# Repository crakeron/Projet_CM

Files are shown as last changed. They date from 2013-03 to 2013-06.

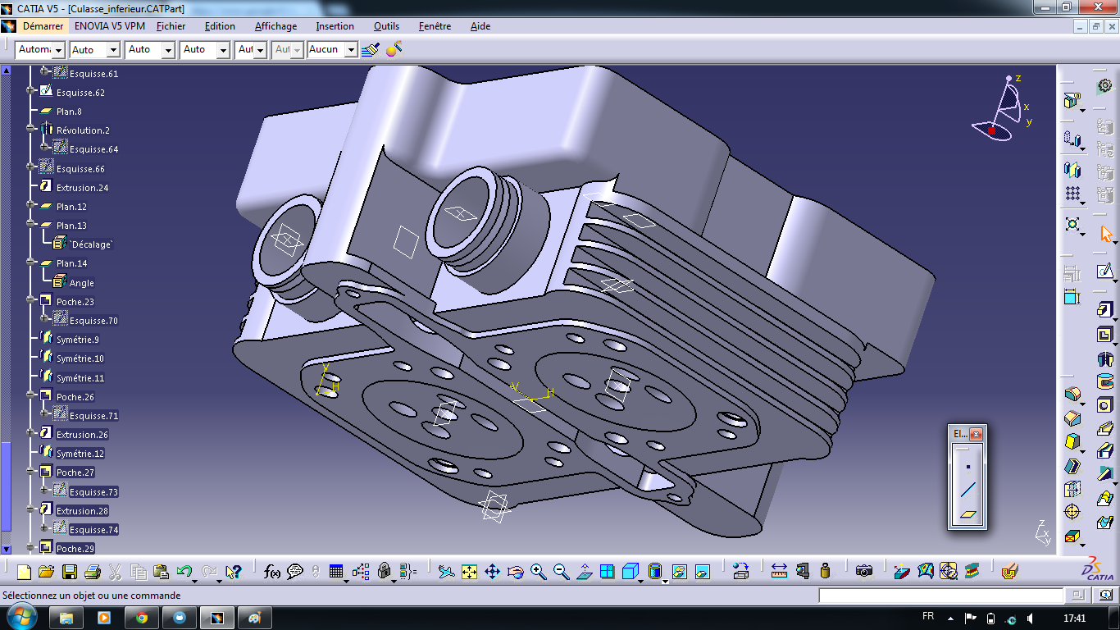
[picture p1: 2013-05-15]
Catia_GPZ500/Photos/7mai_3.png

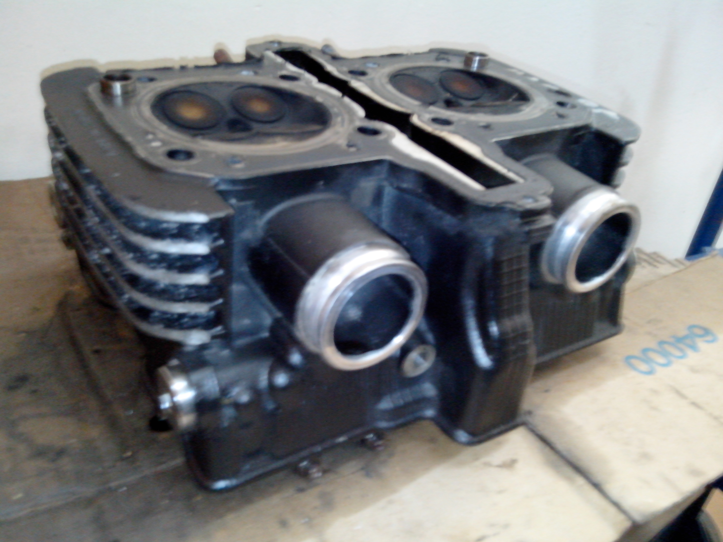
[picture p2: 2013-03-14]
Catia_GPZ500/Photos/Culasse/Culasse.jpg

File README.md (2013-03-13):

Projet_CM
=========

Projet de moteur à soupapes rotatives

Il s'agit ici de fichiers pour le logiciel DS CATIA (V6R20)
Il faut modifier UN SEUL fichier à la fois puis le synchroniser, sinon en cas de retour en arriere, tout un ensemble de 
fichiers differents seront effacés lors du retour en arriere.
.

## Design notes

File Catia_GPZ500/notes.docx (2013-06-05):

Chanfrein pour limiter pertes régulieres en admission/echappement

Pression à l’explosion : contrainte fléchissante. (Effort 10 000N à la détonation)

Rapport de compression : 9.5 -> Pression max ~9.5MPa.

## Section d’admission

Section d’amission à respecter (d’origine) : 2x π.(0.006)²= 2.26.10⁻⁴ m².

AOA à respecter : 22° avant ouverture complète , RFA à respecter : 22° après ouverture complète

Soit en surface latérale, pour un tube de 15mm de rayon :

B=15mm*sin(22°)=5.6mm.

A à calculer pour respecter la section d’admission.

S=π*A*B=2.26.10⁻⁴ m² -→ A=2.26.10⁻⁴ m²/(0.0056*π)=1,3.10⁻² m=13mm

# Dilatation thermique

Pour 100°C<T<390°C : acier a=1,7.10-5 K⁻¹ aluminium : a=2,3.10⁻⁵

dilatation du tube : e=2.5mm. ΔL=1,7.10-5 K⁻¹*(300+273)*2.5=0.02mm

dilatation du chapeau aluminium : ΔL=2,3.10⁻⁵*(300+273)*7=0.9mm

## Joint tresse 3x3 http://www.carrara.it/products.php?main=001&category=030&product=26

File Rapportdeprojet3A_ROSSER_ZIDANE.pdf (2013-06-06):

# Rapport de projet Distribution rotative d’un moteur 4 temps

### Réalisé par :

### - ROSSER Marc - ZIDANE Salim

### Responsable du projet :

### - M.DARCISSAC Sylvain

2012/2013

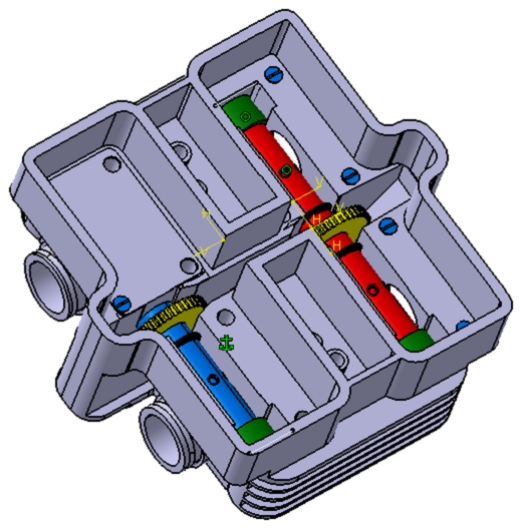
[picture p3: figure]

## 1 ZIDANE Salim – ROSSER Marc

## Sommaire :

I- Introduction : | Erreur ! Signet non défini.
II- Le moteur étudié : | 3
1) Presentation du moteur GPZ500 | 3
2) Données antérieures | 3-4
3) Modélisation du bloc cylindre | 4
III- Système et Assemblage : | 5
IV- Conception : | 7
1) Conception de la culasse | 7
2) Conception du circuit de refroidissement | 9
3) Conception du tube | 10

## 4) Conception des chapeaux d’admission et d’echappement | 11

5) Choix des engrenages | 12
6) Choix des roulements | 14
7) Choix des joints d’etanchéité | 15
V- Conclusion : | 16
ANNEXES | 17-23

## VI- Impression 3D

…24

## 2 ZIDANE Salim – ROSSER Marc

# I Introduction

Dans le cadre de notre préparation au diplôme d'ingénieur en mécanique et conception des systèmes, nous avons été amenés à effectuer notre projet de troisième année sous l’encadrement de M. Sylvain Darcissac.

Ceci est notre premier gros projet, et s’inscrit dans la continuité d’un projet antérieur effectué par un binôme de 5

ème année. Leur projet consistait à supprimer d’un moteur ses soupapes et de les remplacer par un système rotatif. Le moteur en question était un petit moteur de débroussailleuse Honda GX25, monocylindre et à refroidissement à air.

Cette année, nous avions la tache d’imaginer un système rotatif pour l’admission et l’échappement pour un moteur différent. Dans notre cas c’est un vrai moteur de moto, celle du Kawasaki GPZ500.

Plusieurs facteurs sont venus compliquer notre tâche. Premièrement, le moteur n’est plus mono mais bicylindre. Deuxièmement, la taille du moteur (498cm³

), loin des 25cm³
du GX25,
en fait une machine dont la puissance, la chaleur et les forces de détonation sont impérativement à prendre en compte. Enfin, le moteur que nous avons étudié comporte un circuit de refroidissement liquide interne, dont il a fallu reproduire l’effet au mieux.

Conséquence de toutes les différences avec le projet précédent, il était impossible de s’inspirer directement de nos anciens. Nous avons alors imaginé et conçu notre propre système rotatif, présenté dans ce compte rendu.

## Remerciements :

Nous remercions tout d’abord les enseignants qui nous ont encadrés, Sylvain Darcissac et Damien Joli.

Nous tenons également à exprimer notre profonde gratitude à Bernard Brisson, Alain Viale et Michel Roche pour leur attention particulière ainsi que les conseils qu’ils nous ont accordés lors de la réalisation de ce projet. Leur expérience dans la mécanique nous a été d’une grande aide.

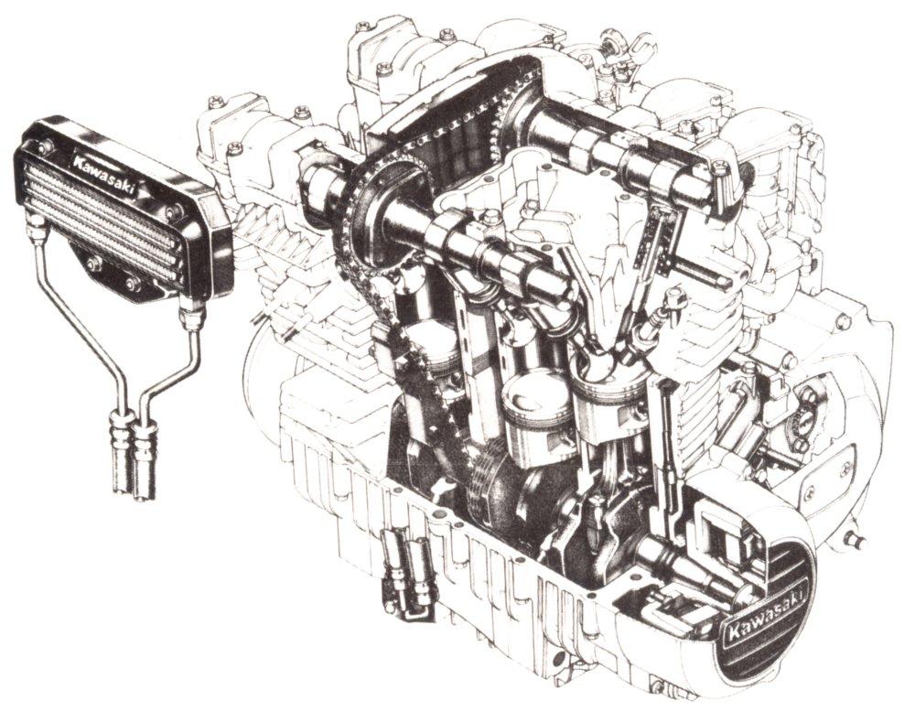
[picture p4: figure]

## 3 ZIDANE Salim – ROSSER Marc

# II. Le moteur étudié

## 1. Présentation

Pour réaliser notre étude et pour servir de base pour notre projet, nous nous sommes servis d’un moteur de Kawasaki GPZ500 (Figure 1)

Il s’agit d’un moteur bicylindre à essence, à refroidissement liquide.

Figure 1 : Le moteur GPZ 500

Figure 2 : Double arbre à came en tête (DOHC)

Les deux arbres à cames sont entraînés en rotation via une chaine de distribution entrainée à partir de l’arbre moteur.

## 2. Données antérieures

D’après les calculs faits par nos camarades plus âgés en 5

ème année, le système actuel de distribution à soupapes engendrerait une perte proche des 7% de la puissance totale d’un moteur (7,7% pour leur moteur de débroussailleuse Honda GX25).
En revanche, les pertes par frottements dues à la rotation de pièces dans leur système était de l’ordre de 0,2% de la puissance totale de leur moteur.
C’est pour cette raison que l’on nous a demandé d’adapter ce système sur un moteur plus gros et à plusieurs cylindres : la GPZ500.

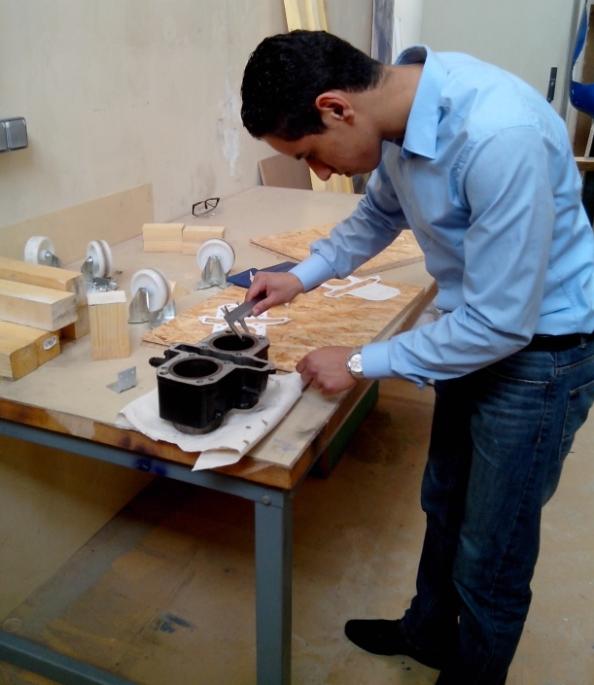
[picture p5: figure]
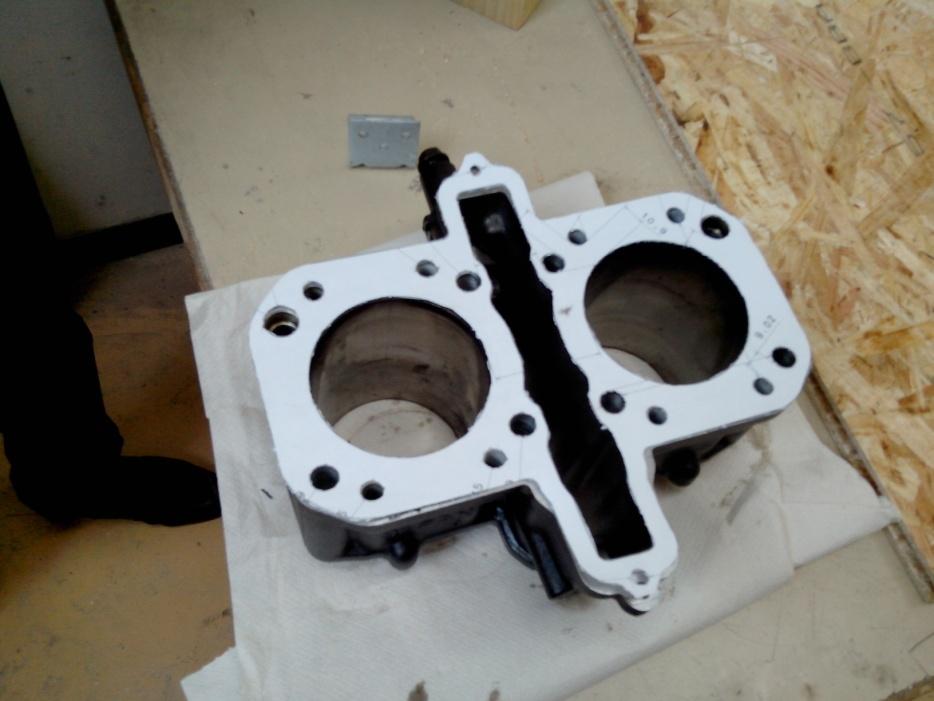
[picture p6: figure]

## 4 ZIDANE Salim – ROSSER Marc

## 3 Modélisation du bloc cylindre

Au cours du projet nous avions eu à concevoir une culasse qui viendrait remplacer celle existante. Il nous fallait être surs de pouvoir fixer celle-ci au moteur. Dans un premier temps, à l’aide d’outils de mesure, nous avions modélisé le bloc moteur en nous concentrant sur sa partie supérieure. Il était impératif que tout soit aligné entre partie supérieure du bloc et partie inférieure de la culasse.

De nombreuses mesures au pied à coulisse ont été nécessaires à la modélisation du bloc moteur, faute de plan disponible

Après impression à l’échelle 1 :1 du plan supérieur de notre modélisation et comparaison avec l’existant, nous sommes satisfaits de la correspondance parfaite

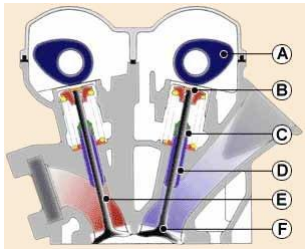
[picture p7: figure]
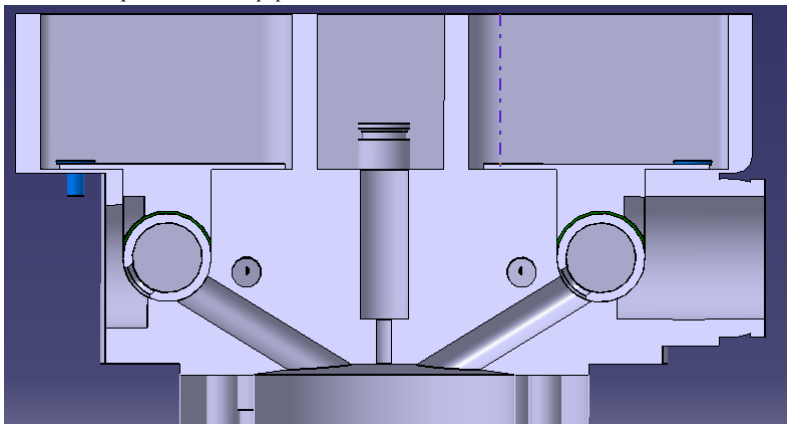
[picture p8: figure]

## 5 ZIDANE Salim – ROSSER Marc

# III Système et Assemblage

## 1) Principe de fonctionnement

Dans un moteur à distribution classique, l’admission et l’échappement sont assurées par des soupapes. Leur ouverture et leur fermeture permettent aux carburant et gaz d’échappement d’entrer ou sortir de la chambre de combustion.

Leur ouverture est assurée par la rotation de l’arbre à cames et ses palets (A). Les soupapes sont mises en translation de quelques millimètres et laissent passer les gaz qu’ils bloquaient.

Dans notre système, des tubes creux ayant une ouverture elliptique sont mis en rotation. Lorsque cette ouverture donne sur la chambre, les fluides contenus dans le tube sont libres de circuler vers celle-ci.

Lorsque le tube est tourné autrement, il bloque l’embouchure et par conséquent remplit le rôle de
« fermeture » qu’aurait une soupape.

Plan de coup de l’accès à la chambre : Le tube de droite correspond à une soupape « ouverte », tandis que le tube de gauche correspond à une soupape fermée. La descente au centre correspond à l’emplacement de la bougie.

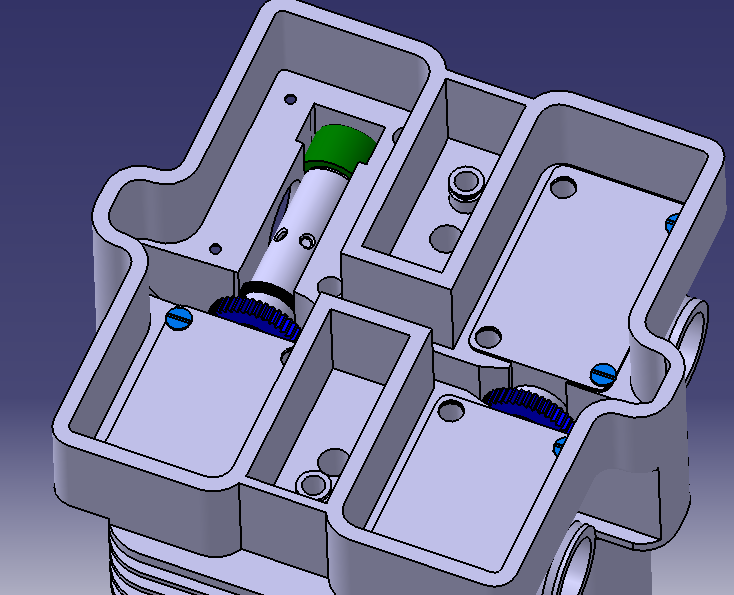
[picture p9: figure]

## 6 ZIDANE Salim – ROSSER Marc

Notre système est constitué de 2 tubes vus ci-dessus, de deux pignons transmettant à ces derniers la rotation de l’arbre moteur, de quatre roulements à aiguilles ainsi que de plusieurs pièces assurant une étanchéité (Joints en carbone, chapeaux de fermeture) et d’une culasse pour loger le tout.

Le cylindre de gauche est en phase d’admission. On y observe l’ouverture elliptique du tube orientée face à l’embouchure de la culasse, permettant ainsi la circulation du gaz depuis l’intérieur du tube vers la chambre en bas. Le cylindre de droite, lui, est fermé : le tube bloque l’embouchure.

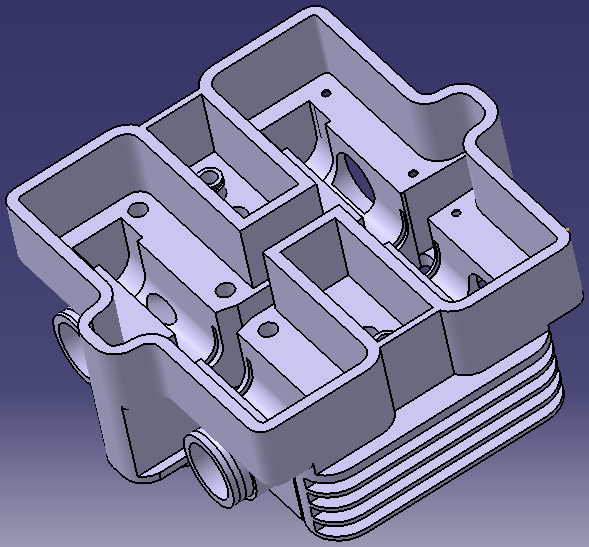
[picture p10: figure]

## 7 ZIDANE Salim – ROSSER Marc

# IV CONCEPTION

## 1) Culasse

La culasse est la pièce principale de notre assemblage. Elle est en aluminium, comme la culasse d’origine et abrite tout le système d’admission.

La taille et la forme des canaux d’admission/échappement ont été calculées afin de respecter celle de la culasse d’origine, afin de laisser suffisamment de carburant entrer dans la chambre par exemple, tout en étant limités par l’encombrement et les avances/retards à la distribution imposées par le constructeur.

L’entrée et l’admission d’origine était assurée par 4 sections circulaires par chambre de combustion (2 chacune. 8 au total pour les deux cylindres) de diamètre 12mm. Nous devions donc choisir une section limitée à 2. π. (6mm)

2 = 226mm² pour chaque fonction.

De plus Kawasaki indique une avance avant ouverture complète et un retard avant fermeture de ± 22°. Sur la section latérale de notre tube de distribution cela ne représente qu’une différence de hauteur de 5,6mm :

Le seul moyen de respecter l’aire avec une hauteur diminuée fut de prendre une forme elliptique dont les dimensions sont les suivantes :

Après conversion en mètres, le calcul de la demi-longueur A de l’ellipse donne A=13mm.

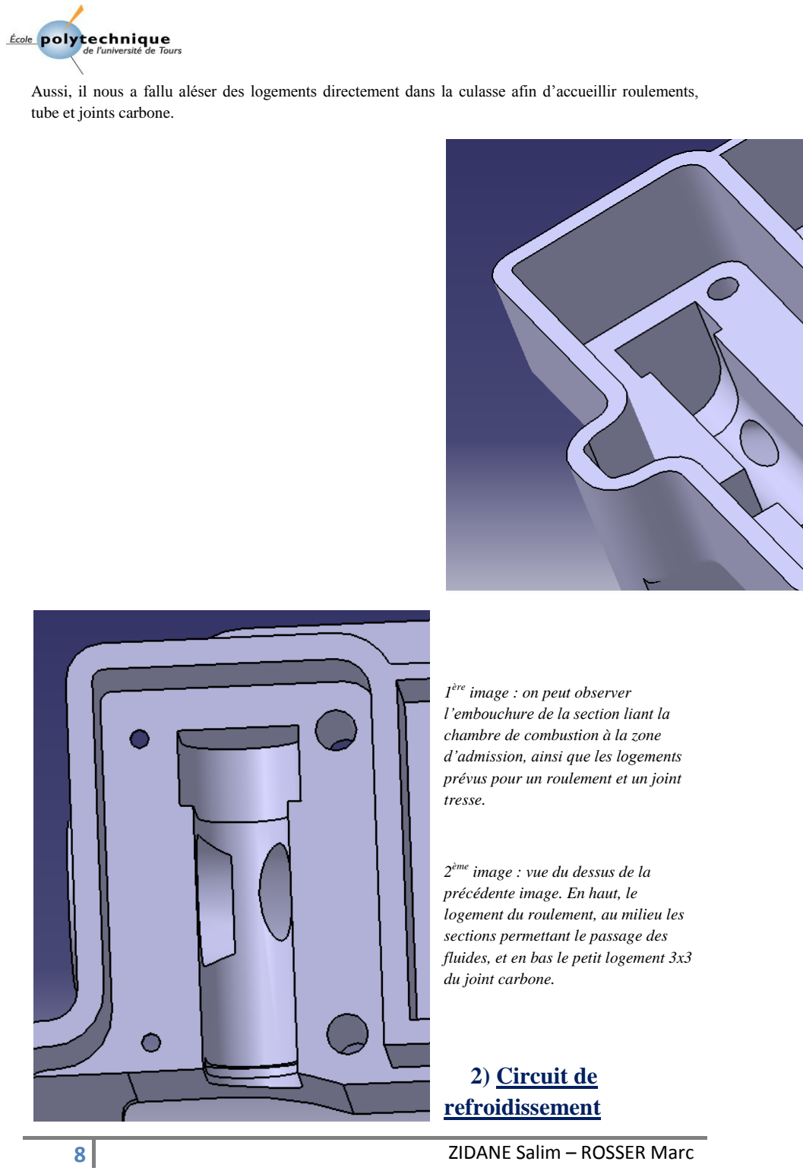
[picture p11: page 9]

## 8 ZIDANE Salim – ROSSER Marc

Aussi, il nous a fallu aléser des logements directement dans la culasse afin d’accueillir roulements, tube et joints carbone.

1

ère image : on peut observer l’embouchure de la section liant la chambre de combustion à la zone d’admission, ainsi que les logements prévus pour un roulement et un joint tresse.

2

ème image : vue du dessus de la précédente image. En haut, le logement du roulement, au milieu les sections permettant le passage des fluides, et en bas le petit logement 3x3 du joint carbone.

## 2) Circuit de refroidissement

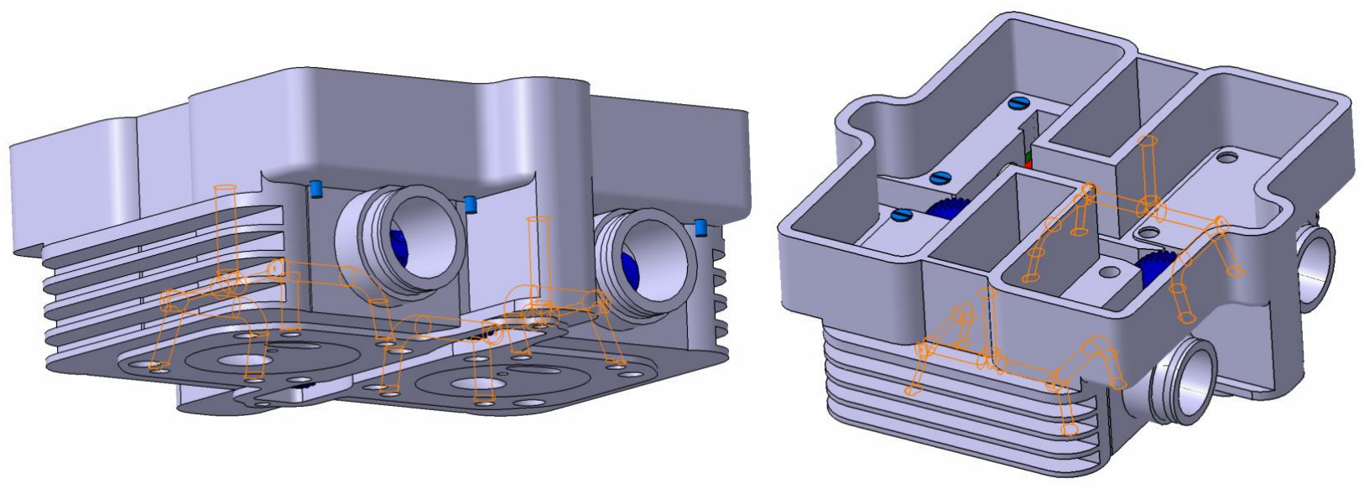
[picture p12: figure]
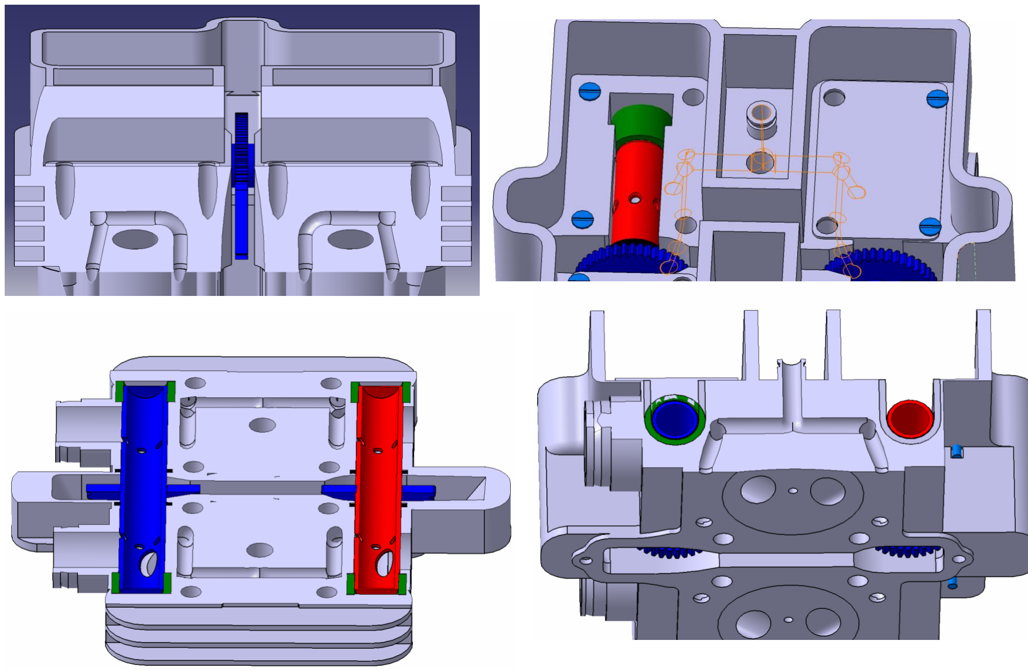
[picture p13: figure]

## 9 ZIDANE Salim – ROSSER Marc

Le circuit de refroidissement d’origine du moteur parcourt le bloc cylindre et traverse la culasse pour s’en extraire sur sa face supérieure. Il nous a donc fallu le prendre en compte et tant bien que de mal en concevoir un qui passe au plus près de la chaleur, et donc des embouchures de la section mentionnée précédemment, malgré le manque de place dû aux éléments nouveaux dans la culasse (roulements, tube, etc). Voici en surligné orange le parcours du circuit et plusieurs plans de coupe afin de se rendre compte de son cheminement:

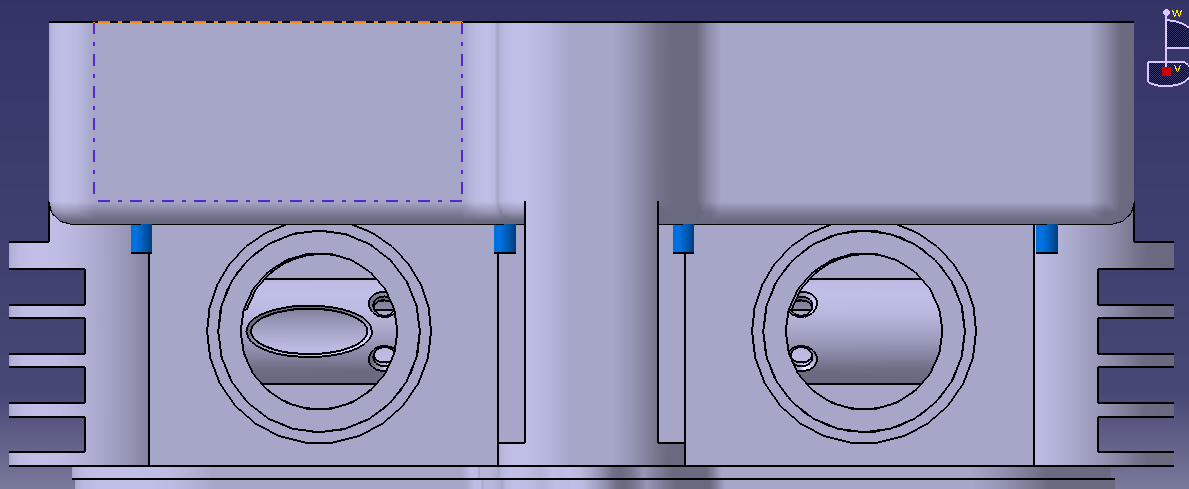
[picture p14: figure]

## 10 ZIDANE Salim – ROSSER Marc

## 3) Tube d’admission ou d’échappement

Nous avons conçu le tube de manière à ce que, lorsqu’il « bloque » l’embouchure à une chambre en phase de compression, les gaz d’échappement ou le mélange air-essence doit pouvoir y rentrer et circuler librement vers le cylindre en phase d’admission/échappement. Il s’agissait de la laisser « ouverte tout en fermant » une chambre de combustion.

A tout instant, grâce à la couronne de petits trous, les fluides peuvent circuler des carburateurs dans le tube ou du tube vers l’échappement. Ces petits trous ne donnent pas accès à la chambre de combustion. Ainsi, dans cette image, le cylindre de droite peut être alimenté par les carburateurs via le tube, tout en gardant le cylindre gauche fermé.

Au vu des températures de fonctionnement et des fluides en circulation (gaz d’échappements), et du passage répété des aiguilles du roulement, le tube sera en acier renforcé ou traité en vue d’améliorer sa durée de vie.

Nous avons appliqué un léger chariotage de 1mm sur les extrémités du tube afin de le bloquer en translation le tube dans l’axe de ses roulements et y aider l’assemblage.

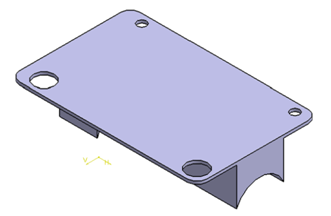
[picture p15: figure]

## 11 ZIDANE Salim – ROSSER Marc

## 4) Chapeaux d’admission et d’échappement

Afin de garantir l’étanchéité des zones d’admission et d’échappement, ainsi que pour empêcher les tubes et roulements de sortir de leur logement, nous avons conçu des « chapeaux » qui ont pour rôle de fermer les zones en question.

Ces chapeaux épousent les formes des pièces avec lesquelles ils sont en contact, à savoir la culasse, les tubes, les roulements et les joints d’étanchéité. Toutefois, nous avons pris en compte la dilatation thermique de cette pièce, et adapté ses dimensions en conséquence.

Les matières sujettes à la dilatation sont l’acier et l’aluminium. Ces derniers ont pour coefficients de dilatation thermique 1,7.10⁻⁵ K

-1

et 2,3.10⁻⁵ K

-1
respectivement.

Nous prenons l’hypothèse que le chapeau est soumis à une température homogène de 300°C, bien que cette homogénéité est peu probable. Une étude de la diffusion de température dans le volume de notre assemblage nous aurait permis de connaitre avec exactitude la température à utiliser. Malheureusement nos connaissances en la matière sont insuffisantes et nous ne sommes pas capables de faire une étude en éléments finies aussi complexe.

L’épaisseur du tube étant de 2,5mm, sa dilatation radiale est de :

ΔL=1,7.10⁻⁵K

-1
*(300+273)*2.5=0.02mm

L’épaisseur radiale maximale du chapeau entre le tube et l’alésage de la culasse étant de 7mm, la dilatation du chapeau à prendre en compte est de :

ΔL=2,3.10⁻⁵K

-1
*(300+273)*7=0.9mm

Nous avons alors retranché 2x 1mm à la largeur du chapeau.

Enfin, un joint plat « carton » sera écrasé entre la culasse et le chapeau par soucis d’étanchéité totale, au vu des températures de fonctionnement et des vibrations.

L’assemblage étant symétrique, il y a deux chapeaux identiques mais symétriques.

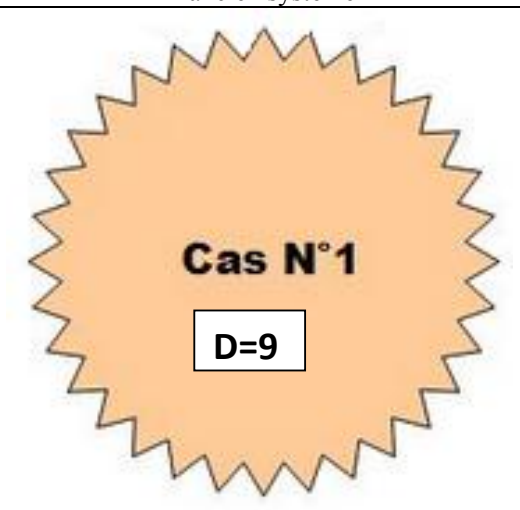
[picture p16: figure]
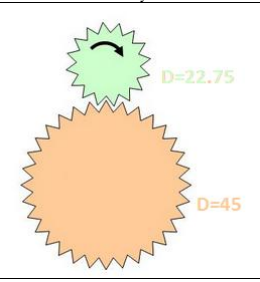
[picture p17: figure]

## 12 ZIDANE Salim – ROSSER Marc

## 5) Choix de l’engrenage

Le pignon d’origine de l’arbre à cames a un diamètre de 90mm. Nous voulons que notre tube conserve la même vitesse de rotation de l’arbre à cames d’origine, afin de garder le synchronisme entre la distribution et les cycles moteurs.

Malheureusement, le pignon de l’ancien système était placé bien plus haut que notre tube dans la culasse. Un diamètre de 90mm ne loge pas dans la culasse au niveau de notre tube. Nous avons dû choisir un engrenage de taille moindre (45mm).

Cela entraine des complications que nous n’avions pas prévues : il faut :

1) S’assurer que la chaine de distribution soit toujours tendue après modification du diamètre des engrenages
2) S’assurer que le tube tourne à la même vitesse de rotation que s’il avait un pignon de 90mm

Afin de remédier à ce problème, il faudrait placer dans notre système un engrenage intermédiaire qui remplirait ce double rôle. Il faut alors calculer le diamètre de cet intermédiaire afin que le rapport de réduction du système final soit équivalent à un unique pignon de 90mm.

L’ancien système | Nouveau système

A noter également que dans notre nouveau système, le sens de rotation des tubes n’est pas une contrainte grâce à leur parfaite symétrie. Il n’est pas dérangeant que les tubes tournent dans un sens opposé, à condition que le calage de la distribution ait été fait pour.

Malheureusement ce pignon intermédiaire et son support n’ont pas été réalisés sur Catia, mais sa dimension a été calculée ci-dessus et il pourrait se situer au milieu de l’installation entre les deux tubes, leur transmettant sa rotation reçue par la chaine de distribution grâce à une petite courroie.

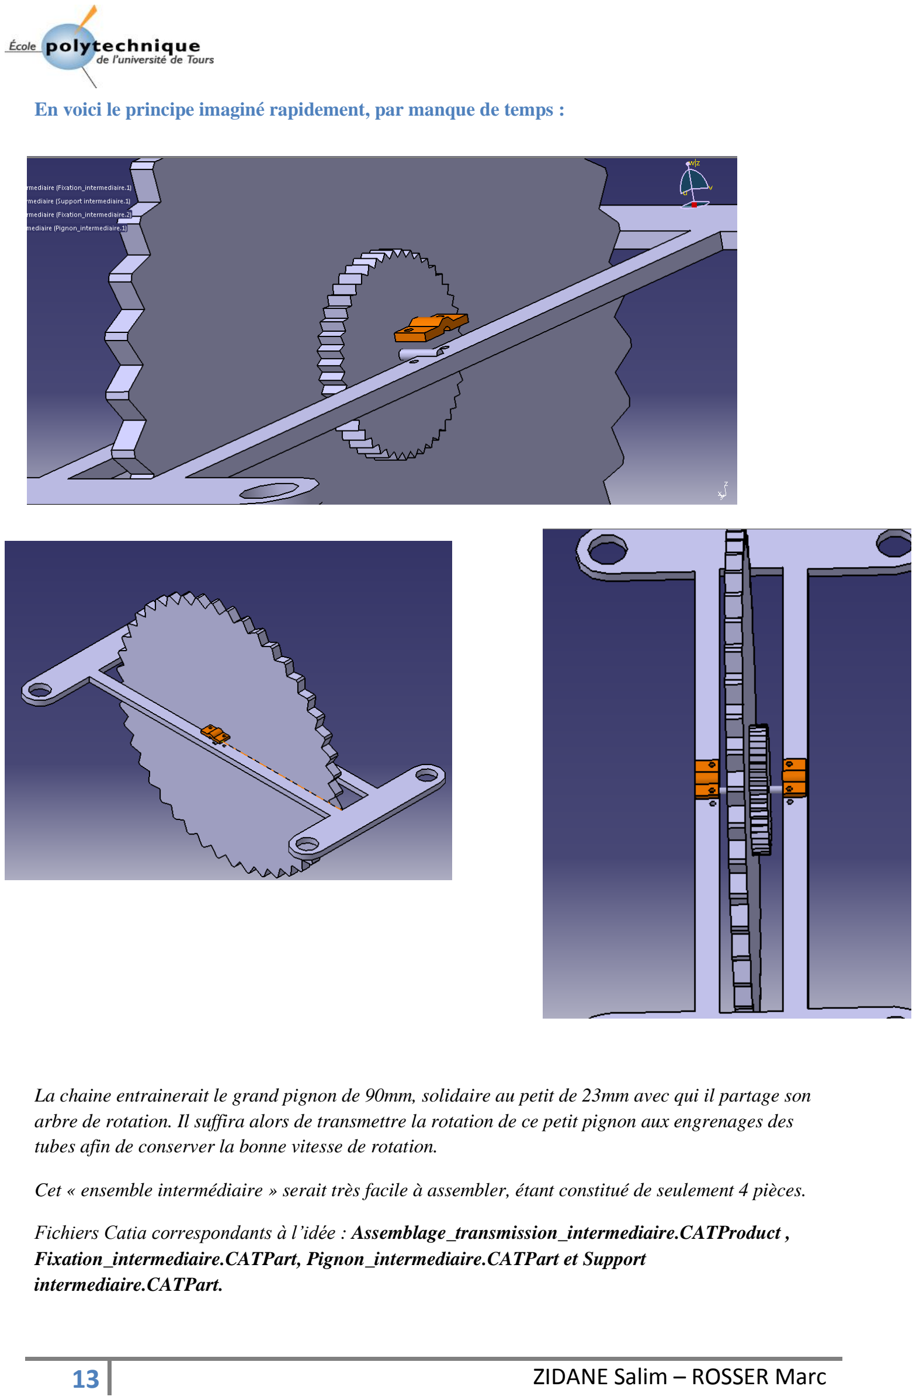
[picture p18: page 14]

## 13 ZIDANE Salim – ROSSER Marc

En voici le principe imaginé rapidement, par manque de temps :

La chaine entrainerait le grand pignon de 90mm, solidaire au petit de 23mm avec qui il partage son arbre de rotation. Il suffira alors de transmettre la rotation de ce petit pignon aux engrenages des tubes afin de conserver la bonne vitesse de rotation.

Cet « ensemble intermédiaire » serait très facile à assembler, étant constitué de seulement 4 pièces.

Fichiers Catia correspondants à l’idée : Assemblage_transmission_intermediaire.CATProduct , Fixation_intermediaire.CATPart, Pignon_intermediaire.CATPart et Support intermediaire.CATPart.

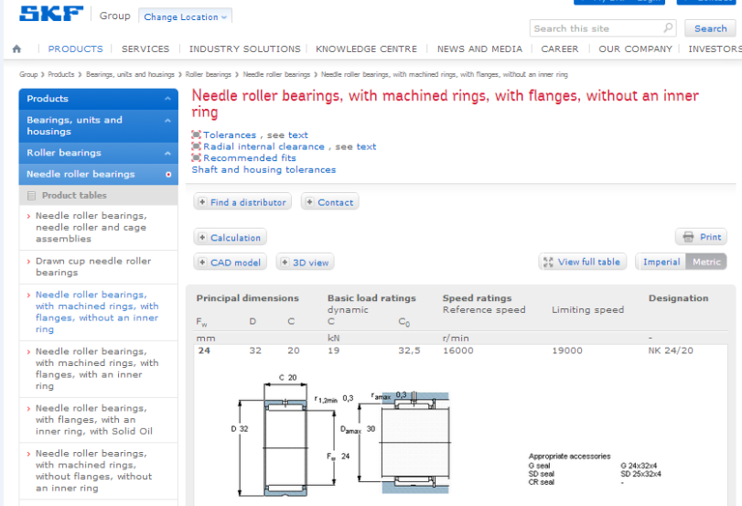
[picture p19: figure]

## 14 ZIDANE Salim – ROSSER Marc

## 6) Le choix des Roulements

Afin de sélectionner nos roulements, nous disposions d’assez peu d’informations quand aux conditions réelles dans lesquelles elles fonctionneraient. Ne connaissant ni la température exacte à laquelle elles seraient soumises, ni la force de l’explosion qu’elles subiraient, nous avons dû les estimer.

- Nous avons estimé pour nos roulements une température de 150°C.
- La notice technique Kawazaki indique un rapport de compression de 9,5 pour ce moteur. En supposant que la pression basse est atmosphérique, nous avons pris une pression s’exerçant sur le tube de 9,5bar. La force radiale induite de cette pression sur la surface elliptique de l’embouchure est ainsi de :

### F = 9,5. 10⁵Pa .2,2610⁻⁴m² = 215N

- La vitesse de rotation maximale de l’arbre moteur d’une moto se trouve être autour de 10,000 tr/min. Le moteur étant 4 temps, nous en avons déduit que les tubes d’admission et d’échappement doivent tourner moitié moins vite.

Ω=5000tr/min

- Le tube a un diamètre de 24mm.
- Dû à l’encombrement, afin de limiter la taille du roulement nous voulions un roulement à aiguilles fines sans bague intérieure. Le matériau du tube a été choisi pour supporter le passage répété des aiguilles.

Le site internet SKF nous a suggéré, après avoir doublé la valeur de la force radiale calculée ci-dessus par mesure
de sécurité, et entré
nos | données | le
roulement suivant :

Le roulement supporte
jusqu’à 16000tr/min,
une charge dynamique
de 19kN, a un rayon
intérieur de 24mm, un
rayon extérieur de
32mm et une largeur de
20mm.

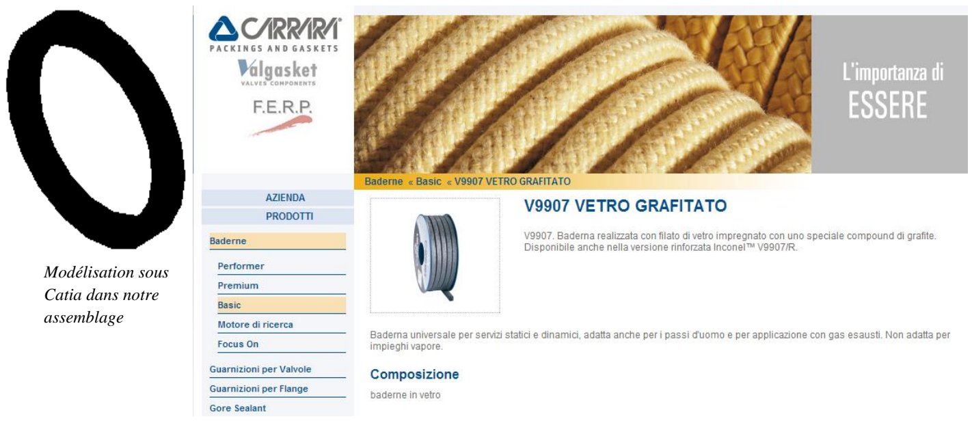
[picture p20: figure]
Modélisation sous Catia dans notre assemblage
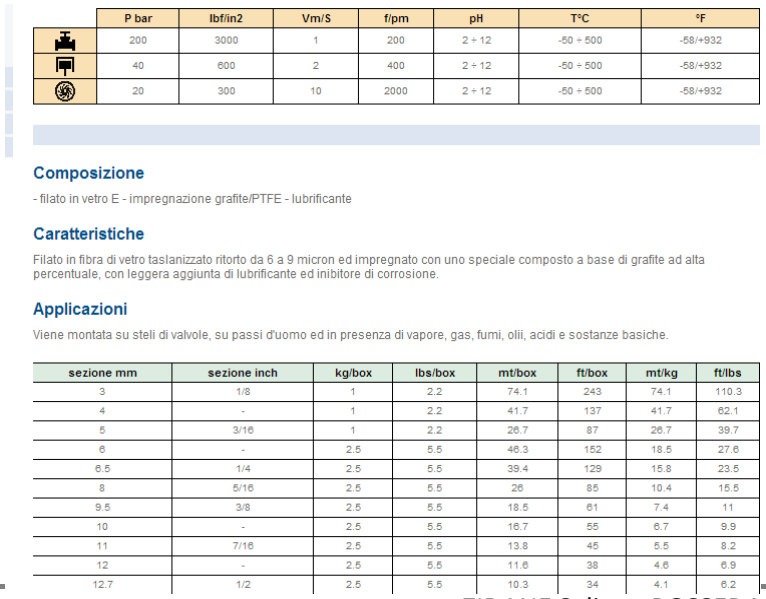
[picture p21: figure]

## 15 ZIDANE Salim – ROSSER Marc

## 7) Les Joints tresses

Une étanchéité totale est nécessaire entre les différentes zones de distribution afin d’ éviter la propagation des gaz, leur mélange ou même leur inflammation.

Par soucis d’étanchéité parfaite dans des conditions de fonctionnement extrêmes due à la rotation des tubes d’admission et aux températures élevées, le joint tresse en graphite de carbone nous semblait être la réponse adaptée. En effet ces derniers sont capables de rendre étanches une surface à des hautes températures, et faciles à installer.

Les joints sélectionnés fonctionnent à une température allant jusqu’à 500°C et sous une pression de 20bar lorsqu’elles assurent l’étanchéité d’un arbre en rotation. Toujours par soucis d’encombrement, nous en avons trouvé des petits dont les dimensions sont de 3mmx3mm.

## 16 ZIDANE Salim – ROSSER Marc

# V Conclusion :

Afin de mener à bien ce projet, nous avons dû approfondir nos connaissances, autant au niveau des calculs théoriques, que pour l’utilisation du logiciel de CAO Catia.

Toutefois, nous pensons que nos connaissances à l’heure actuelle sont insuffisantes pour concevoir des systèmes intégrés à des moteurs thermiques. En effet, il nous aurait fallu connaitre un peu plus la thermique, que ce soit dans un moteur, ainsi que pour calculer la dilatation de toutes les pièces, ou même apprendre à faire des études complexes en éléments finis.

Malgré la difficulté, ce projet nous a permis de nous familiariser avec la démarche de la conception mécanique, et tout de même d’imaginer un système de distribution rotatif qui sur papier fonctionne et a pu être simulé. Le cahier des charges ainsi que nos consignes données ont été tenus, et même si nous sommes conscients que notre système peut ne pas etre parfait dans la pratique, nous avons déjà pensé à quelques pistes d’amélioration :

- Le manque de données, notamment sur la température et la pression, citée en introduction nous a lourdement complexifié la tache. L’idéal afin de dimensionner nos pièces aurait été de faire fonctionner le moteur d’origine en ayant placé des capteurs à plusieurs endroits. Cette expérimentation nous parait faisable à coût limité.
- Le seul moyen de connaître les effets de la dilatation et du fonctionnement du moteur à moyen et long terme serait d’étudier un prototype de notre projet. Ainsi nous pourrions voir rapidement les failles potentielles dans l’étanchéité, la dilatation et la modification du taux de compression du moteur induit par notre nouveau système. Mais cela représente un coût de fabrication non négligeable.

Nous sommes tout de même satisfaits de notre projet et de l’expérience qu’il nous a apporté, et espérons qu’il sera repris et amélioré par des futurs étudiants et peut être verra le jour.

## 17 ZIDANE Salim – ROSSER Marc

# ANNEXES

## 18 ZIDANE Salim – ROSSER Marc

Fournisseur | | BUDGET
Nom | SKF France | | N° COMMANDE / ENGAGEMENT | 1
Adresse complète | Z.A. de l'Observatoire 34 avenue des 3 peuples 78180 Montigny-le-Bretonneux Tel : 01 30 12 73 00 -Fax : 01 30 12 76 50 | | MARCHE
| | | NOMENCLATURE
Projet : | moteur à soupape rotatif | Enseignant : Sylvain Darcissac
Référence | Désignation produits, présentations | Montant unitaire TTC | Quantité | Montant H.T. | Montant T.V.A. | Montant T.T.C.
Needle roller bearing Needle roller bearing Needle roller bearing | NK 24/20 , Fw 24 mm , D 32 mm , C 19 kN , | | 4 | 0,00 | 0,00 | 0,00
| | | | 0,00 | 0,00 | 0,00

Total de la commande
0,00 € | 0,00 € | 0,00 €
Date:
Nom du demandeur

Signature responsable:

19 | ZIDANE Salim – ROSSER Marc Nom | carrara Italy | 2
Projet : | moteur à soupape rotatif
Référence | Désignation produits, présentations | Montant

# unitaire TTC

Quantité | Montant H.T. | Montant T.V.A. Montant T.T.C.
joint tresse | V9907 VETRO GRAFITATO | 4 | 0,00 | 0,00 | 0,00
| | | 0,00 | 0,00 | 0,00
0,00 € | 0,00 € | 0,00 €

# Date: Nom du

# Signature responsable:

# Total de la commande

Fournisseur | BUDGET
| N° COMMANDE / ENGAGEMENT
Adresse complète | Carrara S.p.a. 25030 Adro (BS) - Via Provinciale

# MARCHE

# NOMENCLATURE

# Enseignant : Sylvain Darcissac

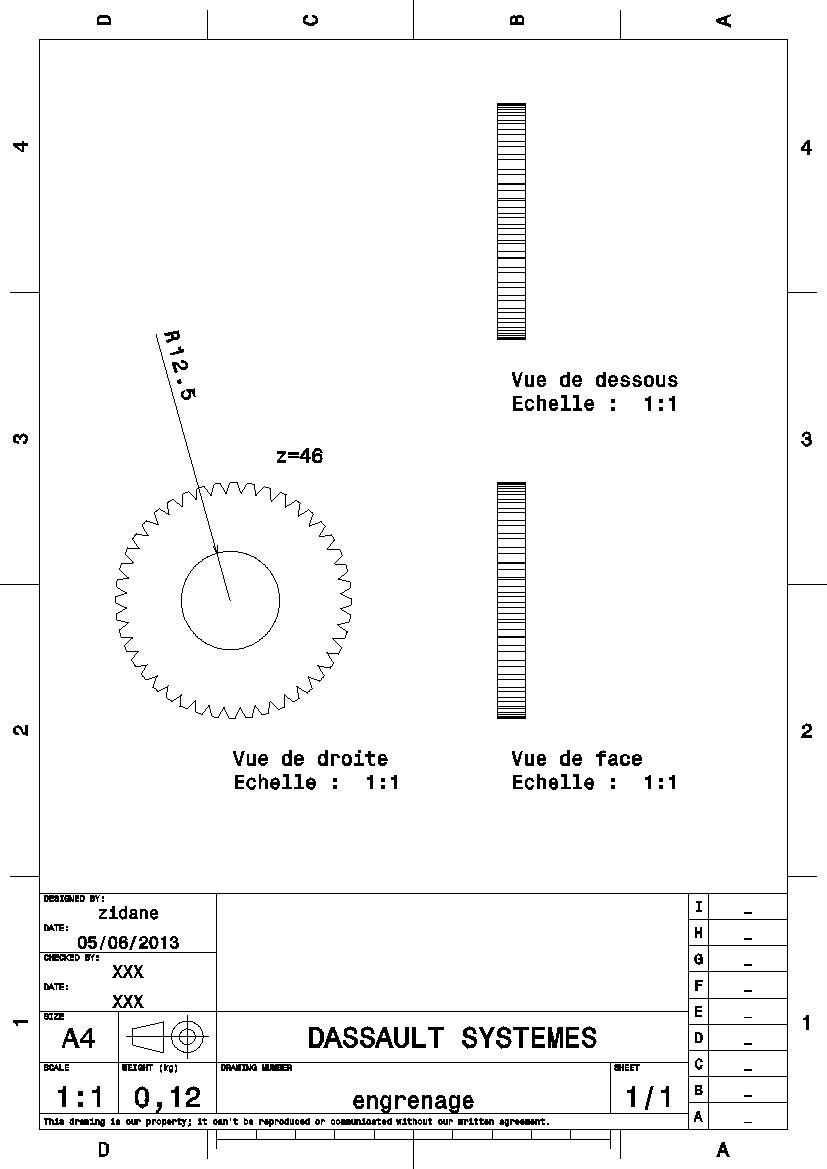
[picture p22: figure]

## 20 ZIDANE Salim – ROSSER Marc

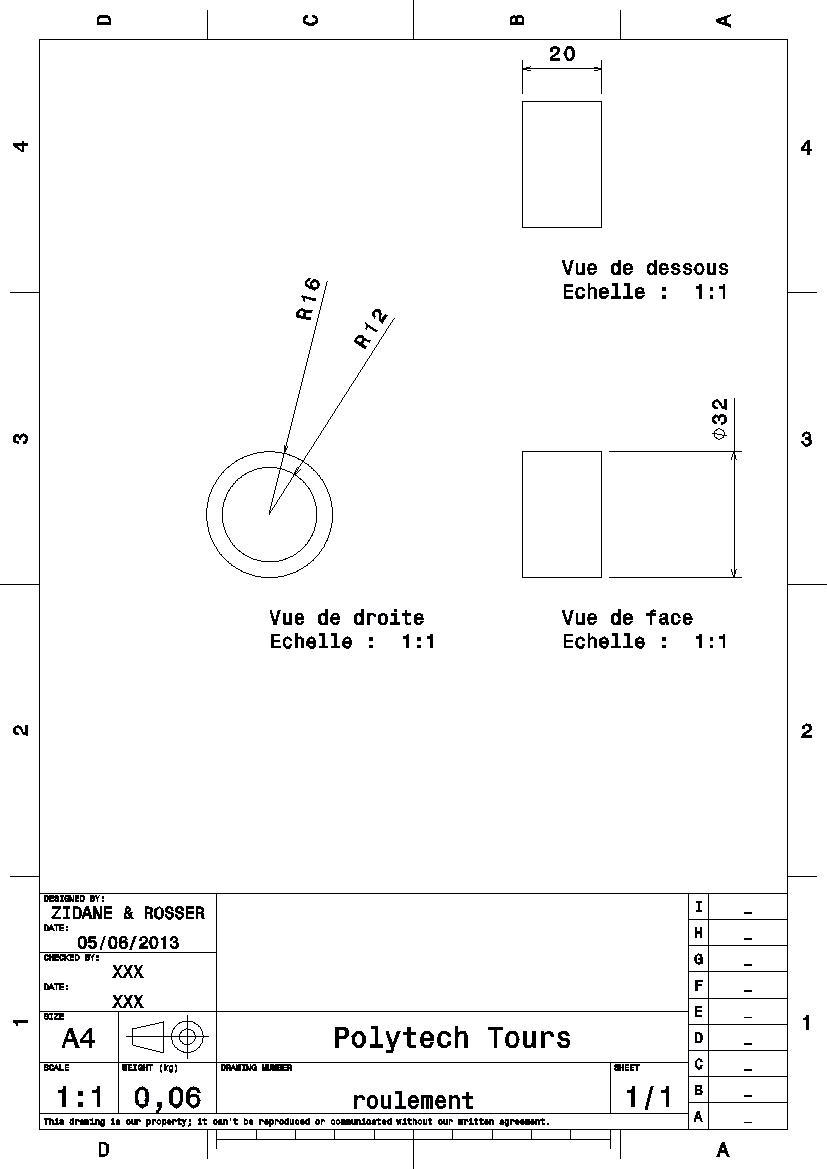
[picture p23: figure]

## 21 ZIDANE Salim – ROSSER Marc

## 22 ZIDANE Salim – ROSSER Marc

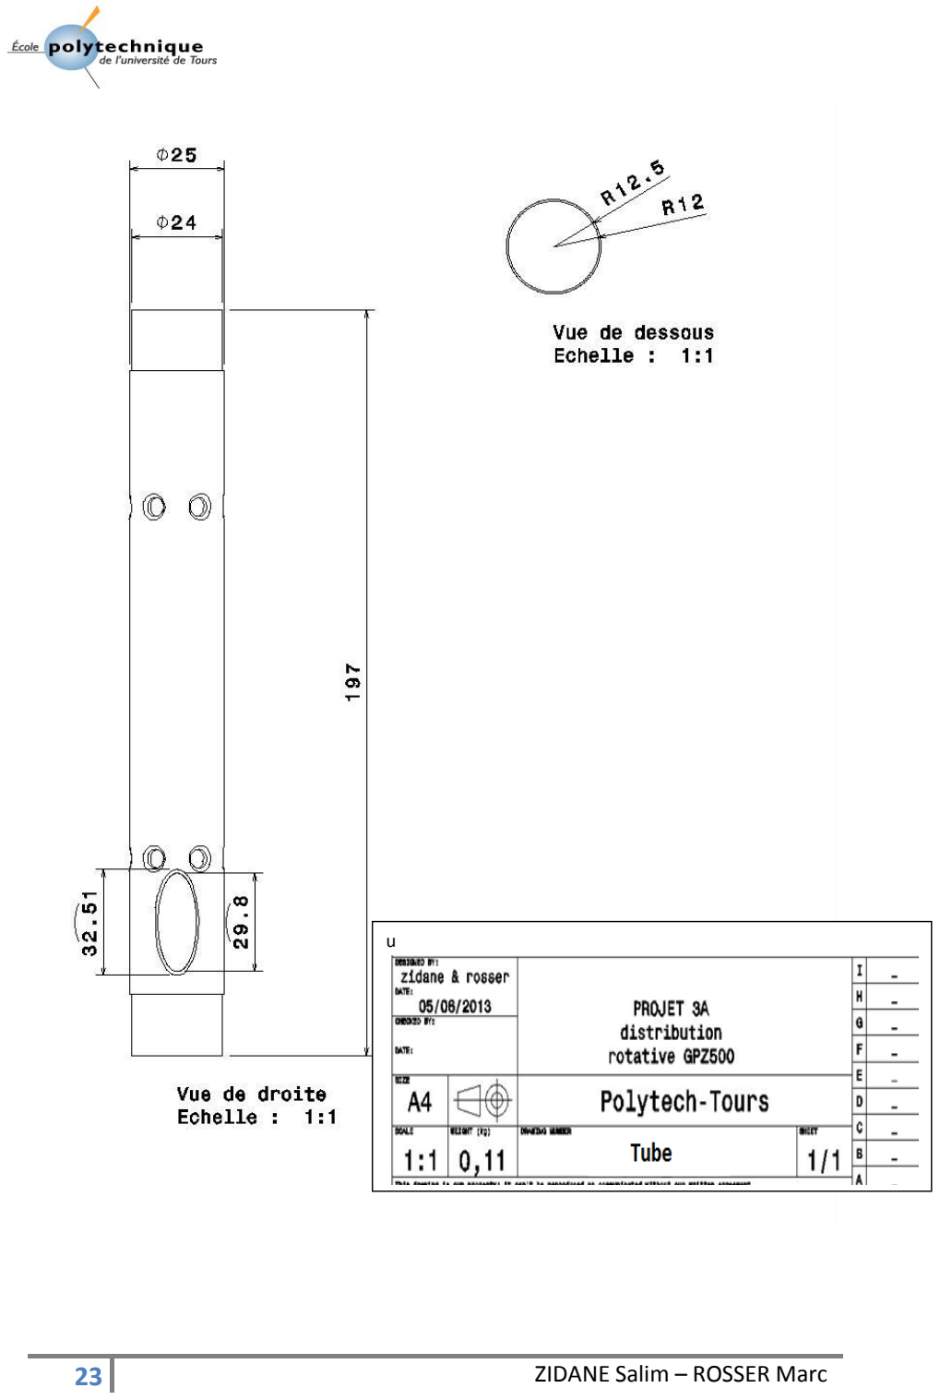
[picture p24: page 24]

## 23 ZIDANE Salim – ROSSER Marc

u

# VI Impression 3D

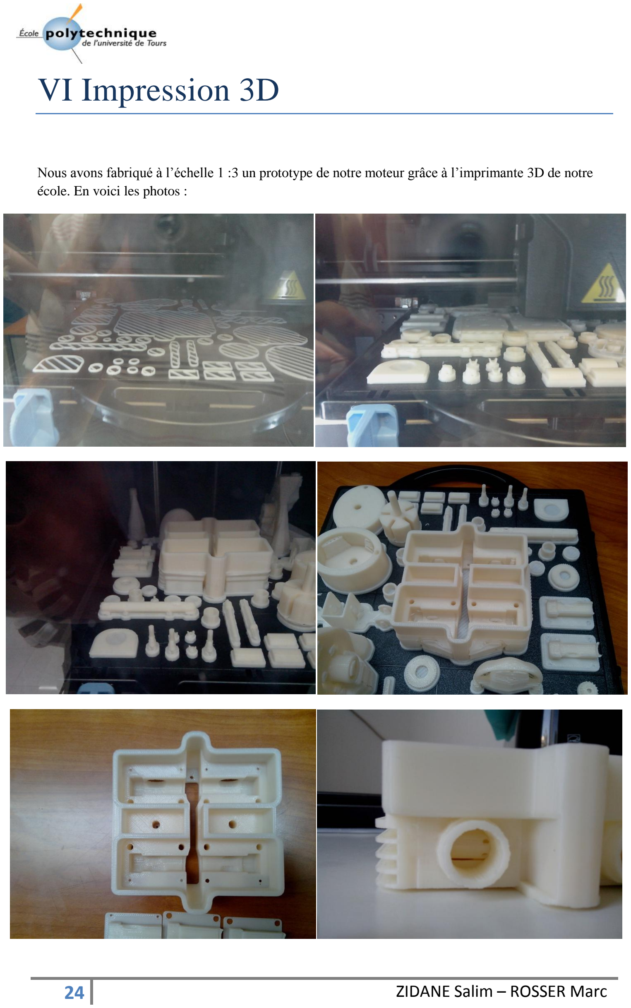
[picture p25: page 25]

## 24 ZIDANE Salim – ROSSER Marc

Nous avons fabriqué à l’échelle 1 :3 un prototype de notre moteur grâce à l’imprimante 3D de notre école. En voici les photos :

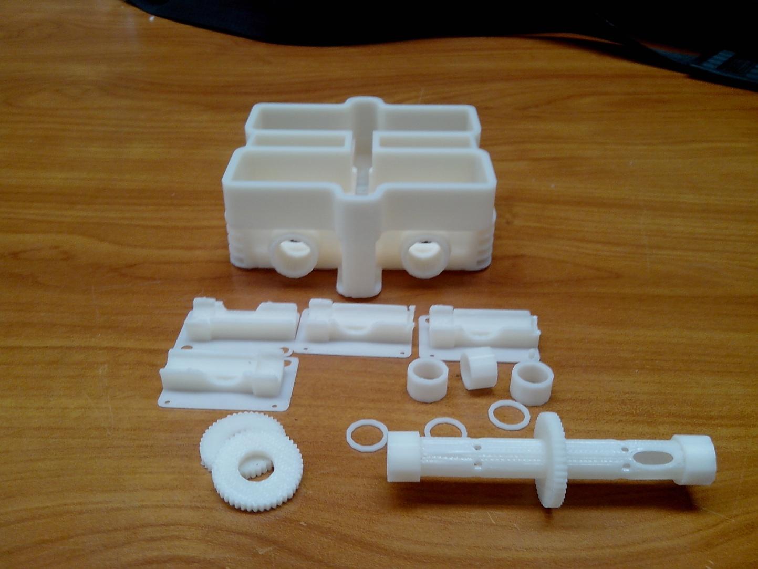
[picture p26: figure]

## 25 ZIDANE Salim – ROSSER Marc

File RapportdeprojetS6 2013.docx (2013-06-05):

2012/2013


Réalisé par :

- ROSSER Marc
- ZIDANE Salim

Responsable du projet :

- M.DARCISSAC Sylvain

Rapport de projet Distribution rotative d’un moteur 4 temps

I. Introduction

Dans le cadre de notre préparation au diplôme d'ingénieur en mécanique et conception des systèmes, nous avons été amenés à effectuer notre projet de troisième année sous l’encadrement de M. DARCISSAC Sylvain.

II. Le moteur étudié

1. Présentation

Pour réaliser notre étude et pour servir de base pour notre projet, nous nous sommes servis d’un moteur de Kawasaki GPZ500 (Figure 1)


Figure 1 : Le moteur GPZ 500

Il s’agit d’un moteur à essence bicylindre à refroidissement liquide


Figure 2 : Double arbre à came en tête (DOHC)

Les deux arbres à came sont entraînés en rotation via une chaine de distribution entrainée à partir de l’arbre moteur.

# LES caractéristique technique Kawasaki GPZ 500


2. information sur la consommation

D’après les calculs faites par des étudiants de la 5 Emme année qui ont fait la conception du moteur à distribution rotative, les pertes par frottement représentent 0,2% de l’énergie totale, contre 7,7% pour un système classique

C’est pour cette raison qu’on pensée à adapter cette conception a notre moteur GPZ 500 et changer le système d’admission du moteur à combustion interne par un système de Distribution rotative

CONCEPTION

## 1) Bloc cylindre


#### Figure : bloc cylindre

## 2) Culasse


## 3) Tubes


## 4) Engrenage


## 5) Le choix des Roulement

Nous nous sommes rendus sur le site de l’entreprise SKF pour trouver un ROULEMENT à aiguilles en lui donnant toutes les informations qui correspondent à notre système.


## 6) Joint tresse

## Une étanchéité est réalisée entre la chambre pour éviter la propagation de gaz.

## elle est réalisée entre la chambre de combustion et le reste du système pour cela on a donc utilisé 2 joints tresse qu’on a dessinés avec les dimensions exacts et que nous utiliserons au niveau du tube comme suite :


## 7) Chapeaux

Pour empêcher les tubes de sortir du bâti à cause de la pression exercée par l’explosion, on a dû donc pensé à mettre des chapeaux.

On a aussi mis sur le chapeau la même forme des tubes qui sert au bien guider en mouvement de rotation.


## 8) Le système de refroidissement


Canalisation de refroidissement


## 9) Assemblage_GPZ500

Après avoir dessiné toutes les pièces nécessaires pour notre système, on a pu faire l’assemblage comme vous pouvez le voir ci-dessous :

Nous avons simulés le système qui a parfaitement marchée et qu’on montrera lors de la soutenance.

# I- Conclusion :

Pour mener à bien ce projet, nous avons dû approfondir nos connaissances autant de point de vue calculs théoriques que de point de vue conception sur le logiciel CATIA.

De plus, ce projet nous a permis de nous familiariser avec la démarche de création d’un système de distribution rotatif qui va peut-être servir à l’entreprise visée. En effet, nous avons pu développer un système qui respect tous les consignes fournis par cette dernière en collaborant avec M.Darcissac Sylvain, notre tuteur qui nous a suivi tout au long de notre projet.

Nous avons été confrontés à de nombreux problèmes et dans la plupart des cas nous avons pu trouver une solution alternative afin de les résoudre complètement. En effet, les résultats de simulation sont tout à fait satisfaisants.

# ANNEXES

ZIDANE - ROSSER 3A DMS 2012-2013

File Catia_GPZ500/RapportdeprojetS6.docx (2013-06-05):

2012/2013


Réalisé par :

- ROSSER Marc
- ZIDANE Salim

Responsable du projet :

- M.DARCISSAC Sylvain

Rapport de projet Distribution rotative d’un moteur 4 temps

I. Introduction

Dans le cadre de notre préparation au diplôme d'ingénieur en mécanique et conception des systèmes, nous avons été amenés à effectuer notre projet de troisième année sous l’encadrement de M. DARCISSAC Sylvain.

II. Le moteur étudié

1. Présentation

Pour réaliser notre étude et pour servir de base pour notre projet, nous nous sommes servis d’un moteur de Kawasaki GPZ500 (Figure 1)


Figure 1 : Le moteur GPZ 500

Il s’agit d’un moteur à essence bicylindre à refroidissement liquide


Figure 2 : Double arbre à came en tête (DOHC)

Les deux arbres à came sont entraînés en rotation via une chaine de distribution entrainée à partir de l’arbre moteur.

2. information sur la consommation

D’après les calculs faites par des étudiants de la 5 Emme année qui ont fait la conception du moteur à distribution rotative, les pertes par frottement représentent 0,2% de l’énergie totale, contre 7,7% pour un système classique

C’est pour cette raison qu’on pensée à adapter cette conception a notre moteur GPZ 500 et changer le système d’admission du moteur à combustion interne par un système de Distribution rotative

CONCEPTION

## 1) Bloc cylindre


#### Figure : bloc cylindre

## 2) Culasse


## 3) Tubes


## 4) Engrenage


## 5) Le choix des Roulement

Nous nous sommes rendus sur le site de l’entreprise SKF pour trouver un ROULEMENT à aiguilles en lui donnant toutes les informations qui correspondent à notre système.


## 6) Joint tresse

## Une étanchéité est réalisée entre la chambre pour éviter la propagation de gaz.

## elle est réalisée entre la chambre de combustion et le reste du système pour cela on a donc utilisé 2 joints tresse qu’on a dessinés avec les dimensions exacts et que nous utiliserons au niveau du tube comme suite :


## 7) Chapeaux

Pour empêcher les tubes de sortir du bâti à cause de la pression exercée par l’explosion, on a dû donc pensé à mettre des chapeaux.

On a aussi mis sur le chapeau la même forme des tubes qui sert au bien guider en mouvement de rotation.


## 8) Le système de refroidissement


Canalisation de refroidissement


## 9) Assemblage_GPZ500

Après avoir dessiné toutes les pièces nécessaires pour notre système, on a pu faire l’assemblage comme vous pouvez le voir ci-dessous :

Nous avons simulés le système qui a parfaitement marchée et qu’on montrera lors de la soutenance.

# I- Conclusion :

Pour mener à bien ce projet, nous avons dû approfondir nos connaissances autant de point de vue calculs théoriques que de point de vue conception sur le logiciel CATIA.

De plus, ce projet nous a permis de nous familiariser avec la démarche de création d’un système de distribution rotatif qui va peut-être servir à l’entreprise visée. En effet, nous avons pu développer un système qui respect tous les consignes fournis par cette dernière en collaborant avec M.Darcissac Sylvain, notre tuteur qui nous a suivi tout au long de notre projet.

Nous avons été confrontés à de nombreux problèmes et dans la plupart des cas nous avons pu trouver une solution alternative afin de les résoudre complètement. En effet, les résultats de simulation sont tout à fait satisfaisants.

# ANNEXES

ZIDANE - ROSSER 3A DMS 2012-2013

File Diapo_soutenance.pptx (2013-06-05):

## Projet 3A Polytech Tours

Le moteur à admission et échappement rotatifs


Marc Rosser
Salim Zidane

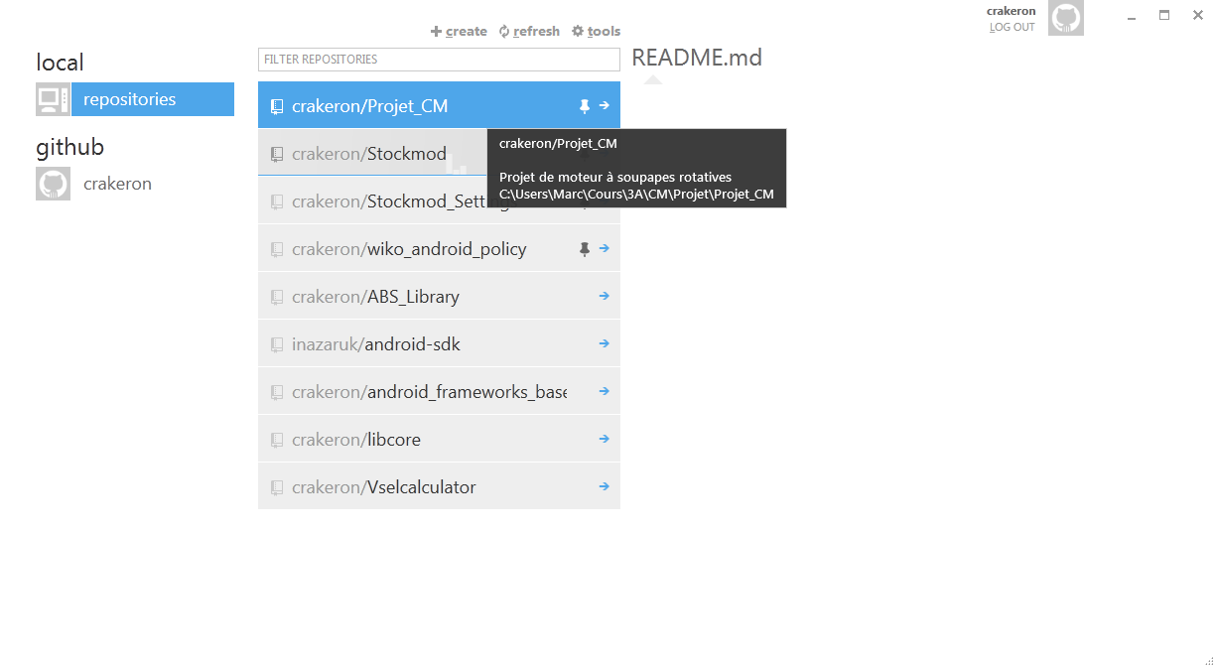
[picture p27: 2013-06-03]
Catia_GPZ500/Photos/Github_main.png

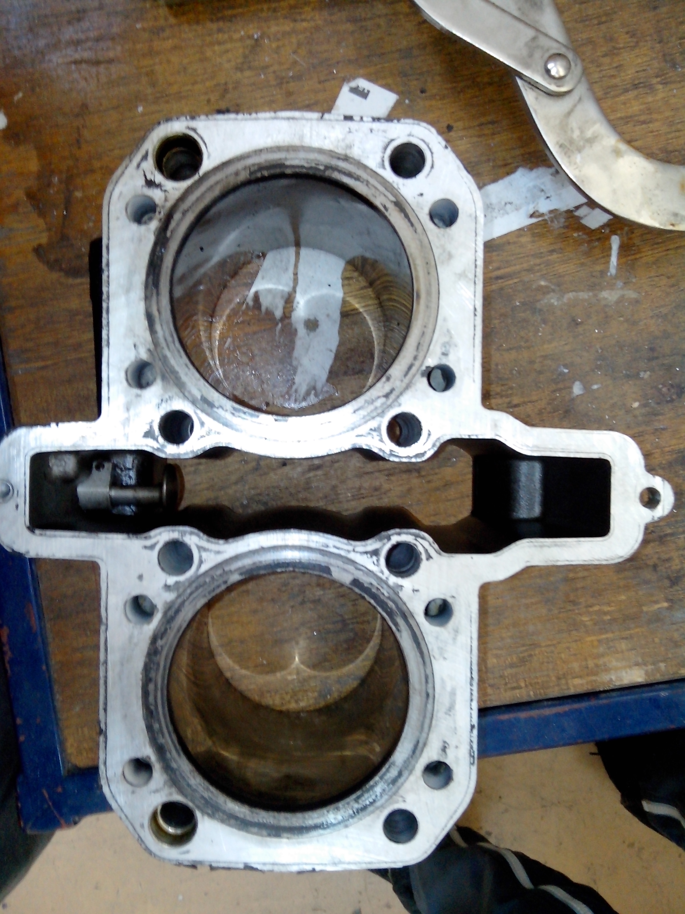
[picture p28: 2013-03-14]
Catia_GPZ500/Photos/Bloc Cylindre/Bloc_Cylindre_dessus_normale_2.jpg

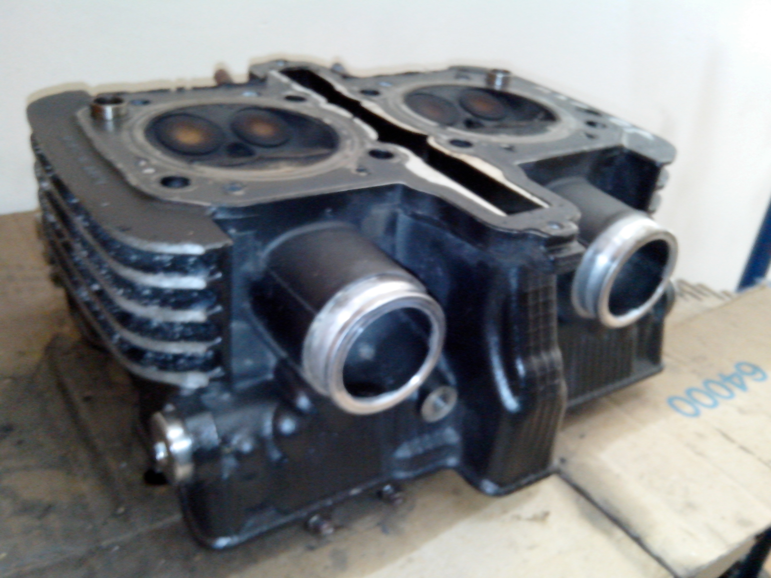
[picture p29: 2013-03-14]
Catia_GPZ500/Photos/Culasse/Culasse (2).jpg

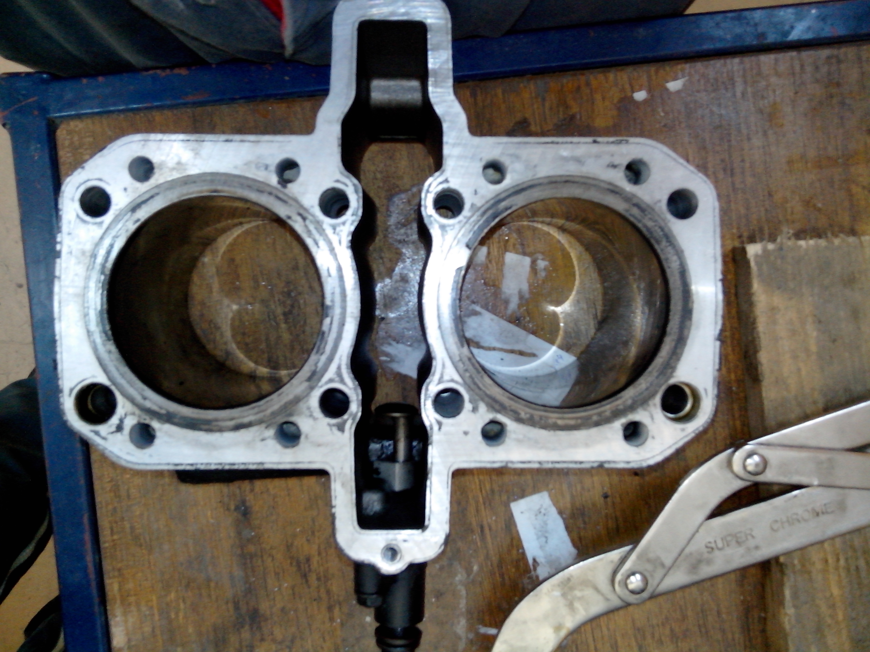
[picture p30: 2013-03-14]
Catia_GPZ500/Photos/Bloc Cylindre/Bloc_Cylindre_dessus_normale.jpg

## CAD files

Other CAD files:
Catia_GPZ500/Assemblage_GPZ500.CATProduct
Catia_GPZ500/Bloc_cylindre_V3.CATPart
Catia_GPZ500/Culasse.CATPart
Catia_GPZ500/Culasse_inferieur.CATPart
Catia_GPZ500/Vis.CATPart
Catia_GPZ500/chapeau1.CATPart
Catia_GPZ500/chapeau2.CATPart
Catia_GPZ500/engrenage.CATPart
Catia_GPZ500/intermidiaire tube_aiguilles.CATPart
Catia_GPZ500/joint tresse .CATPart
Catia_GPZ500/roulement.CATPart
Catia_GPZ500/tube.CATPart
Catia_GX25/Assemblage.CATProduct
Catia_GX25/Reniflard.CATPart

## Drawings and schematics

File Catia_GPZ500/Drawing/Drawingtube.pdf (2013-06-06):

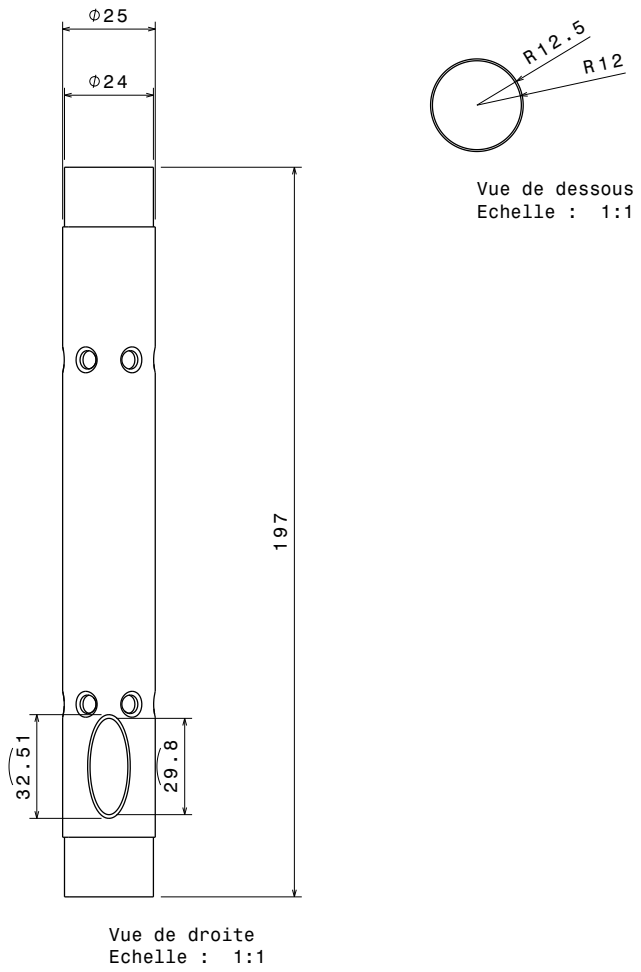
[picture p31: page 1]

Vue de dessous
Echelle : 1:1

Vue de droite

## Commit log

2013-03-13 caché reniflard
    [Reniflard.CATPart]
2013-03-13 Revert "caché reniflard"
    This reverts commit c3a4dbab350e05afc95d02a8acb291cfdb9703a3.
    [Reniflard.CATPart]
2013-03-13 defait test
    [Assemblage.CATProduct, Reniflard.CATPart]
2013-03-14 Ajout des photos du bloc cylindre + culasse
    Pour création pièce Catia
2013-03-14 Cotation premiere de l'image du bloc-cylindre
2013-03-14 Début de modélisation du bloc cylindre
    [Bloc_cylindre.CATPart]
2013-03-14 Bloc principal
    [Bloc_Cylindre.CATProduct, Bloc_cylindre.CATPart]
2013-03-15 Transparence du calque
    [Bloc_Cylindre.CATProduct]
2013-03-15 Fin de toutes les cotations bloc cylindre (up)
    [Bloc_cylindre_V3.CATPart]
2013-03-15 Fermeture et extrusion de la piece
    Obtention d'un bloc primitif
    [Bloc_cylindre_V3.CATPart]
2013-03-15 Correction du lamage
    [Bloc_cylindre_V3.CATPart]
2013-03-15 Arrondi des 4 coins exterieurs
    [Bloc_cylindre_V3.CATPart]
2013-03-15 fin des arretes
    [Bloc_cylindre_V3.CATPart]
2013-03-15 Bloc cylindre fini
    [Bloc_cylindre_V3.CATPart]
2013-03-15 correction d'un rayon
    [Bloc_cylindre_V3.CATPart]
2013-03-15 Arrondi intérieur (bas)
    [Bloc_cylindre_V3.CATPart]
2013-03-15 Suppression des anciennes versions du bloc cylind
    [Bloc_Cylindre.CATProduct, Bloc_cylindre.CATPart]
2013-03-15 Correction d'appelation de fichiers
    Cotations sur le drawing, pour vérification à l'école
2013-03-18 Modification rayon de courbure arrondi superieure
    [Bloc_cylindre_V3.CATPart]
2013-03-22 de la merde
    [Bloc_cylindre_V3.CATPart]
2013-03-22 Revert "de la merde"
    This reverts commit 48b15b0a9200078b3fb1f796951c99de452fcf9e.
    [Bloc_cylindre_V3.CATPart]
2013-03-22 Correction n1
    [Bloc_cylindre_V3.CATPart]
2013-03-22 correction de la piece + drawing
    [Bloc_cylindre_V3.CATPart]
2013-03-22 Fin de la modélisation du bloc cylindre
2013-03-22 correction empattement bas
    [Bloc_cylindre_V3.CATPart]
2013-03-29 Ajout de l'assemblage, début de la culasse
    [Assemblage_GPZ500.CATProduct, Bloc_cylindre_V3.CATPart, Culasse_inferieure.CATPart]
2013-03-29 début modelisation culasse inférieure
    [Culasse_inferieure.CATPart]
2013-03-29 Isolement de la partie bougie
    [Culasse_inferieure.CATPart]
2013-03-29 Modélisation continu...
    [Culasse_inferieure.CATPart]
2013-04-09 rajout du tube
    [tube.CATPart]
2013-04-09 Extrusion pour cylindres d'arrivé
    [Culasse_inferieure.CATPart]
2013-04-09 gorges d'admission
    [Culasse_inferieure.CATPart]
2013-04-09 interieur en cours
    [Culasse_inferieure.CATPart]
2013-04-09 interieur fini
    [Culasse_inferieure.CATPart]
2013-04-09 arretes, reste1 correction
    [Culasse_inferieure.CATPart]
2013-04-09 fin des corrections
    [Culasse_inferieure.CATPart]
2013-04-21 1ère modélisation (idée) des tubes d'admission
    [tube.CATPart]
2013-04-22 tube plus réaliste
    [tube.CATPart]
2013-04-22 backup de la culasse existante avant nos modification
    [Culasse.CATPart, Culasse_inferieure.CATPart]
2013-04-22 renommage de culasse_inf en culasse
    Nous allons arreter d'utiliser culasse, pour la concevoir en deux
    parties, supérieure et inférieure
    [Culasse_inferieure.CATPart]
2013-04-22 début
    [Culasse_inferieur.CATPart]
2013-04-23 Essai pour l'admission
    Probleme du circuit d'eau toujours d'actualité
    [Culasse_inferieur.CATPart]
2013-05-07 logement tube d'admission
    [Culasse_inferieur.CATPart]
2013-05-15 Ajout de notes
    [tube.CATPart]
2013-05-15 Bombage des tetes de chambres
2013-05-15 Ajout des revues techniques Kawazaki
2013-05-15 tube int
    [intermidiaire tube_aiguilles.CATPart]
2013-05-15 Modification du tube (l'ellipse choisie)
    [tube.CATPart]
2013-05-15 Modifications pour harmonie
    [Assemblage_GPZ500.CATProduct, tube.CATPart]
2013-05-17 enregistré tout
    [Assemblage_GPZ500.CATProduct, tube.CATPart]
2013-05-17 Fini liaison chambre-adm/echap
    [Assemblage_GPZ500.CATProduct, tube.CATPart]
2013-05-29 modification du tube
    Alesage, préparation du chapeau, logement des roulements
    [tube.CATPart]
2013-05-29 debut du chapeau
    [Assemblage_GPZ500.CATProduct, chapeau.CATPart, tube.CATPart]
2013-05-29 Revert "sqdf"
    This reverts commit e056c787597fed596585eb0baf79e918e0d62db3.
    [chapeau.CATPart]
2013-05-29 Revert "Revert "sqdf""
    This reverts commit 602a2de82c6c29786401dccd465612b6d0101452.
    [chapeau.CATPart]
2013-05-29 chapeau fini
    [Assemblage_GPZ500.CATProduct, chapeau.CATPart]
2013-05-29 roulement
    De 32
    Di 24
    [roulement.CATPart]
2013-05-29 renamed chapeau to chapeau1
    [chapeau.CATPart, chapeau1.CATPart]
2013-05-29 engrenage
    D 86
    [engrenage.CATPart]
2013-05-29 joint tresse
    4*4
    [joint tresse .CATPart]
2013-05-29 assemblage quasi fini
    [Assemblage_GPZ500.CATProduct, Bloc_cylindre_V3.CATPart, chapeau2.CATPart]
2013-05-29 congés d'arete sur les chapeaux
    [chapeau1.CATPart, chapeau2.CATPart]
2013-05-29 modification du joint, du chapeau pour le loger...
    [Assemblage_GPZ500.CATProduct, chapeau1.CATPart, engrenage.CATPart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]
2013-05-29 Joints tresses faits
    [Assemblage_GPZ500.CATProduct, chapeau1.CATPart, tube.CATPart]
2013-05-30 Assemblage quasi fini, DMU not OK
    Materiaux appliqués aux pieces
    [Assemblage_GPZ500.CATProduct, Bloc_cylindre_V3.CATPart, Vis.CATPart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]
2013-05-30 Liaisons en cours
    [Assemblage_GPZ500.CATProduct, joint tresse .CATPart]
2013-05-30 Simul OK
    [Assemblage_GPZ500.CATProduct]
2013-05-30 Simulation,assemblage, sections TERMINEES
    [Assemblage_GPZ500.CATProduct, chapeau1.CATPart, roulement.CATPart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]
2013-05-31 Ready for simu (sauf eau)
    [Assemblage_GPZ500.CATProduct, chapeau1.CATPart]
2013-05-31 Circuit d'eau fini!
    [Assemblage_GPZ500.CATProduct, Bloc_cylindre_V3.CATPart]
2013-05-31 Ajout de sections, préparation pour soutenance
    [Assemblage_GPZ500.CATProduct, Bloc_cylindre_V3.CATPart, chapeau1.CATPart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]
2013-06-03 Prise de photos pour soutenance
    Divers images du circuitd'eau
2013-06-05 Préparation de la soutenance
2013-06-05 Mise en place de code couleur
    [Assemblage_GPZ500.CATProduct]
